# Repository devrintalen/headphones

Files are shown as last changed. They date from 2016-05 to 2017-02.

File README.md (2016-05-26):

Headphones
----------

I've always wanted to make my own headphones.  And I've wanted to tackle a more serious board design than my previous designs.  So I've tackled both with this project, codenamed NYC.

Design
======

These are no ordinary headphones.  I've built in an entire digital processing pipeline to do all sorts of crazy things.  They're essentially a set of headphones with a built-in codec—but because nobody makes open-source codecs, I've rolled my own using an FPGA.  It uses an ADC to digitize the input and a DAC to convert it back to analog, along with a hi-fi headphone amp design from Texas Instruments.

I've written a few blog posts about the design and architecture, and have a few in-depth bits about the ADC and DAC, so far.  See [this post][1], which includes an up-to-date list of the pieces I've written.

[1]: http://blog.devrintalen.net/first-draft-of-headphones/

I find the idea of having a DSP built into headphones to be pretty cool.  I don't know how I'll take advantage of that yet, but I see at least having access to an EQ over the USB connection.  Heck, maybe I'll put a bunch of knobs on the cans to give you physical access.  Anything's possible now.

Status
======

Right now the schematics have been mostly nailed down.  I'm currently laying out a development board (dubbed NYCDB-01) to test out the design and run a proof-of-concept.

Files
=====

This repository is sectioned off into the following paths:

* `docs/` is where I keep datasheets and spreadsheets.
* `pcb/` has the KiCad schematics and board layout for the development board.  In the future this will be renamed to allow there to be another folder for the product board.
* `sim/` right now has `ngspice` circuits and `gnuplot` scripts to simulate the ADC and DAC.  There's a `Makefile` in there to batch run the simulations.

Contributions
=============

Contributions are of course welcome and appreciated.  Board design is usually a one-person sport, so that may not be the best place to help out, but suggestions for the schematics are helpful.  This project is licensed under the GNU GPLv3.

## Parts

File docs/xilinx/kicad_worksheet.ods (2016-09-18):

P144 | 0 | TL | IO_L1P_HSWAPEN_0 | 0 | 0 | B | X IO_L1P_HSWAPEN_0 144 0 0 300 R 50 50 1 1 B
P143 | 0 | TL | IO_L1N_VREF_0 | 0 | 100 | B | X IO_L1N_VREF_0 143 0 100 300 R 50 50 1 1 B
P142 | 0 | TL | IO_L2P_0 | 0 | 200 | B | X IO_L2P_0 142 0 200 300 R 50 50 1 1 B
P141 | 0 | TL | IO_L2N_0 | 0 | 300 | B | X IO_L2N_0 141 0 300 300 R 50 50 1 1 B
P140 | 0 | TL | IO_L3P_0 | 0 | 400 | B | X IO_L3P_0 140 0 400 300 R 50 50 1 1 B
P139 | 0 | TL | IO_L3N_0 | 0 | 500 | B | X IO_L3N_0 139 0 500 300 R 50 50 1 1 B
P138 | 0 | TL | IO_L4P_0 | 0 | 600 | B | X IO_L4P_0 138 0 600 300 R 50 50 1 1 B
P137 | 0 | TL | IO_L4N_0 | 0 | 700 | B | X IO_L4N_0 137 0 700 300 R 50 50 1 1 B
P134 | 0 | TL | IO_L34P_GCLK19_0 | 0 | 800 | B | X IO_L34P_GCLK19_0 134 0 800 300 R 50 50 1 1 B
P133 | 0 | TL | IO_L34N_GCLK18_0 | 0 | 900 | B | X IO_L34N_GCLK18_0 133 0 900 300 R 50 50 1 1 B
P132 | 0 | TL | IO_L35P_GCLK17_0 | 0 | 1000 | B | X IO_L35P_GCLK17_0 132 0 1000 300 R 50 50 1 1 B
P131 | 0 | TL | IO_L35N_GCLK16_0 | 0 | 1100 | B | X IO_L35N_GCLK16_0 131 0 1100 300 R 50 50 1 1 B
P127 | 0 | TR | IO_L36P_GCLK15_0 | 0 | 1200 | B | X IO_L36P_GCLK15_0 127 0 1200 300 R 50 50 1 1 B
P126 | 0 | TR | IO_L36N_GCLK14_0 | 0 | 1300 | B | X IO_L36N_GCLK14_0 126 0 1300 300 R 50 50 1 1 B
P124 | 0 | TR | IO_L37P_GCLK13_0 | 0 | 1400 | B | X IO_L37P_GCLK13_0 124 0 1400 300 R 50 50 1 1 B
P123 | 0 | TR | IO_L37N_GCLK12_0 | 0 | 1500 | B | X IO_L37N_GCLK12_0 123 0 1500 300 R 50 50 1 1 B
P121 | 0 | TR | IO_L62P_0 | 0 | 1600 | B | X IO_L62P_0 121 0 1600 300 R 50 50 1 1 B
P120 | 0 | TR | IO_L62N_VREF_0 | 0 | 1700 | B | X IO_L62N_VREF_0 120 0 1700 300 R 50 50 1 1 B
P119 | 0 | TR | IO_L63P_SCP7_0 | 0 | 1800 | B | X IO_L63P_SCP7_0 119 0 1800 300 R 50 50 1 1 B
P118 | 0 | TR | IO_L63N_SCP6_0 | 0 | 1900 | B | X IO_L63N_SCP6_0 118 0 1900 300 R 50 50 1 1 B
P117 | 0 | TR | IO_L64P_SCP5_0 | 0 | 2000 | B | X IO_L64P_SCP5_0 117 0 2000 300 R 50 50 1 1 B
P116 | 0 | TR | IO_L64N_SCP4_0 | 0 | 2100 | B | X IO_L64N_SCP4_0 116 0 2100 300 R 50 50 1 1 B
P115 | 0 | TR | IO_L65P_SCP3_0 | 0 | 2200 | B | X IO_L65P_SCP3_0 115 0 2200 300 R 50 50 1 1 B
P114 | 0 | TR | IO_L65N_SCP2_0 | 0 | 2300 | B | X IO_L65N_SCP2_0 114 0 2300 300 R 50 50 1 1 B
P112 | 0 | TR | IO_L66P_SCP1_0 | 0 | 2400 | B | X IO_L66P_SCP1_0 112 0 2400 300 R 50 50 1 1 B
P111 | 0 | TR | IO_L66N_SCP0_0 | 0 | 2500 | B | X IO_L66N_SCP0_0 111 0 2500 300 R 50 50 1 1 B
P109 | NA | NA | TCK | 0 | 2600 | I | X TCK 109 0 2600 300 R 50 50 1 1 I
P110 | NA | NA | TDI | 0 | 2700 | I | X TDI 110 0 2700 300 R 50 50 1 1 I
P107 | NA | NA | TMS | 0 | 2800 | I | X TMS 107 0 2800 300 R 50 50 1 1 I
P106 | NA | NA | TDO | 0 | 2900 | O | X TDO 106 0 2900 300 R 50 50 1 1 O
P105 | 1 | RT | IO_L1P_1 | 0 | 3000 | B | X IO_L1P_1 105 0 3000 300 R 50 50 1 1 B
P104 | 1 | RT | IO_L1N_VREF_1 | 0 | 3100 | B | X IO_L1N_VREF_1 104 0 3100 300 R 50 50 1 1 B
P102 | 1 | RT | IO_L32P_1 | 0 | 3200 | B | X IO_L32P_1 102 0 3200 300 R 50 50 1 1 B
P101 | 1 | RT | IO_L32N_1 | 0 | 3300 | B | X IO_L32N_1 101 0 3300 300 R 50 50 1 1 B
P100 | 1 | RT | IO_L33P_1 | 0 | 3400 | B | X IO_L33P_1 100 0 3400 300 R 50 50 1 1 B
P99 | 1 | RT | IO_L33N_1 | 0 | 3500 | B | X IO_L33N_1 99 0 3500 300 R 50 50 1 1 B
P98 | 1 | RT | IO_L34P_1 | 0 | 3600 | B | X IO_L34P_1 98 0 3600 300 R 50 50 1 1 B
P97 | 1 | RT | IO_L34N_1 | 0 | 3700 | B | X IO_L34N_1 97 0 3700 300 R 50 50 1 1 B
P95 | 1 | RT | IO_L40P_GCLK11_1 | 0 | 3800 | B | X IO_L40P_GCLK11_1 95 0 3800 300 R 50 50 1 1 B
P94 | 1 | RT | IO_L40N_GCLK10_1 | 0 | 3900 | B | X IO_L40N_GCLK10_1 94 0 3900 300 R 50 50 1 1 B
P93 | 1 | RT | IO_L41P_GCLK9_IRDY1_1 | 0 | 4000 | B | X IO_L41P_GCLK9_IRDY1_1 93 0 4000 300 R 50 50 1 1 B
P92 | 1 | RT | IO_L41N_GCLK8_1 | 0 | 4100 | B | X IO_L41N_GCLK8_1 92 0 4100 300 R 50 50 1 1 B
P88 | 1 | RB | IO_L42P_GCLK7_1 | 0 | 4200 | B | X IO_L42P_GCLK7_1 88 0 4200 300 R 50 50 1 1 B
P87 | 1 | RB | IO_L42N_GCLK6_TRDY1_1 | 0 | 4300 | B | X IO_L42N_GCLK6_TRDY1_1 87 0 4300 300 R 50 50 1 1 B
P85 | 1 | RB | IO_L43P_GCLK5_1 | 0 | 4400 | B | X IO_L43P_GCLK5_1 85 0 4400 300 R 50 50 1 1 B
P84 | 1 | RB | IO_L43N_GCLK4_1 | 0 | 4500 | B | X IO_L43N_GCLK4_1 84 0 4500 300 R 50 50 1 1 B
P83 | 1 | RB | IO_L45P_1 | 0 | 4600 | B | X IO_L45P_1 83 0 4600 300 R 50 50 1 1 B
P82 | 1 | RB | IO_L45N_1 | 0 | 4700 | B | X IO_L45N_1 82 0 4700 300 R 50 50 1 1 B
P81 | 1 | RB | IO_L46P_1 | 0 | 4800 | B | X IO_L46P_1 81 0 4800 300 R 50 50 1 1 B
P80 | 1 | RB | IO_L46N_1 | 0 | 4900 | B | X IO_L46N_1 80 0 4900 300 R 50 50 1 1 B
P79 | 1 | RB | IO_L47P_1 | 0 | 5000 | B | X IO_L47P_1 79 0 5000 300 R 50 50 1 1 B
P78 | 1 | RB | IO_L47N_1 | 0 | 5100 | B | X IO_L47N_1 78 0 5100 300 R 50 50 1 1 B
P75 | 1 | RB | IO_L74P_AWAKE_1 | 0 | 5200 | B | X IO_L74P_AWAKE_1 75 0 5200 300 R 50 50 1 1 B
P74 | 1 | RB | IO_L74N_DOUT_BUSY_1 | 0 | 5300 | B | X IO_L74N_DOUT_BUSY_1 74 0 5300 300 R 50 50 1 1 B
P73 | NA | NA | SUSPEND | 0 | 5400 | I | X SUSPEND 73 0 5400 300 R 50 50 1 1 I
P72 | 2 | NA | CMPCS_B_2 | 0 | 5500 | N | X CMPCS_B_2 72 0 5500 300 R 50 50 1 1 N
P71 | 2 | NA | DONE_2 | 0 | 5600 | B | X DONE_2 71 0 5600 300 R 50 50 1 1 B
P70 | 2 | BR | IO_L1P_CCLK_2 | 0 | 5700 | B | X IO_L1P_CCLK_2 70 0 5700 300 R 50 50 1 1 B
P69 | 2 | BR | IO_L1N_M0_CMPMISO_2 | 0 | 5800 | B | X IO_L1N_M0_CMPMISO_2 69 0 5800 300 R 50 50 1 1 B
P67 | 2 | BR | IO_L2P_CMPCLK_2 | 0 | 5900 | B | X IO_L2P_CMPCLK_2 67 0 5900 300 R 50 50 1 1 B
P66 | 2 | BR | IO_L2N_CMPMOSI_2 | 0 | 6000 | B | X IO_L2N_CMPMOSI_2 66 0 6000 300 R 50 50 1 1 B
P65 | 2 | BR | IO_L3P_D0_DIN_MISO_MISO1_2 | 0 | 6100 | B | X IO_L3P_D0_DIN_MISO_MISO1_2 65 0 6100 300 R 50 50 1 1 B
P64 | 2 | BR | IO_L3N_MOSI_CSI_B_MISO0_2 | 0 | 6200 | B | X IO_L3N_MOSI_CSI_B_MISO0_2 64 0 6200 300 R 50 50 1 1 B
P62 | 2 | BR | IO_L12P_D1_MISO2_2 | 0 | 6300 | B | X IO_L12P_D1_MISO2_2 62 0 6300 300 R 50 50 1 1 B
P61 | 2 | BR | IO_L12N_D2_MISO3_2 | 0 | 6400 | B | X IO_L12N_D2_MISO3_2 61 0 6400 300 R 50 50 1 1 B
P60 | 2 | BR | IO_L13P_M1_2 | 0 | 6500 | B | X IO_L13P_M1_2 60 0 6500 300 R 50 50 1 1 B
P59 | 2 | BR | IO_L13N_D10_2 | 0 | 6600 | B | X IO_L13N_D10_2 59 0 6600 300 R 50 50 1 1 B
P58 | 2 | BR | IO_L14P_D11_2 | 0 | 6700 | B | X IO_L14P_D11_2 58 0 6700 300 R 50 50 1 1 B
P57 | 2 | BR | IO_L14N_D12_2 | 0 | 6800 | B | X IO_L14N_D12_2 57 0 6800 300 R 50 50 1 1 B
P56 | 2 | BR | IO_L30P_GCLK1_D13_2 | 0 | 6900 | B | X IO_L30P_GCLK1_D13_2 56 0 6900 300 R 50 50 1 1 B
P55 | 2 | BR | IO_L30N_GCLK0_USERCCLK_2 | 0 | 7000 | B | X IO_L30N_GCLK0_USERCCLK_2 55 0 7000 300 R 50 50 1 1 B
P51 | 2 | BL | IO_L31P_GCLK31_D14_2 | 0 | 7100 | B | X IO_L31P_GCLK31_D14_2 51 0 7100 300 R 50 50 1 1 B
P50 | 2 | BL | IO_L31N_GCLK30_D15_2 | 0 | 7200 | B | X IO_L31N_GCLK30_D15_2 50 0 7200 300 R 50 50 1 1 B
P48 | 2 | BL | IO_L48P_D7_2 | 0 | 7300 | B | X IO_L48P_D7_2 48 0 7300 300 R 50 50 1 1 B
P47 | 2 | BL | IO_L48N_RDWR_B_VREF_2 | 0 | 7400 | B | X IO_L48N_RDWR_B_VREF_2 47 0 7400 300 R 50 50 1 1 B
P46 | 2 | BL | IO_L49P_D3_2 | 0 | 7500 | B | X IO_L49P_D3_2 46 0 7500 300 R 50 50 1 1 B
P45 | 2 | BL | IO_L49N_D4_2 | 0 | 7600 | B | X IO_L49N_D4_2 45 0 7600 300 R 50 50 1 1 B
P44 | 2 | BL | IO_L62P_D5_2 | 0 | 7700 | B | X IO_L62P_D5_2 44 0 7700 300 R 50 50 1 1 B
P43 | 2 | BL | IO_L62N_D6_2 | 0 | 7800 | B | X IO_L62N_D6_2 43 0 7800 300 R 50 50 1 1 B
P41 | 2 | BL | IO_L64P_D8_2 | 0 | 7900 | B | X IO_L64P_D8_2 41 0 7900 300 R 50 50 1 1 B
P40 | 2 | BL | IO_L64N_D9_2 | 0 | 8000 | B | X IO_L64N_D9_2 40 0 8000 300 R 50 50 1 1 B
P39 | 2 | BL | IO_L65P_INIT_B_2 | 0 | 8100 | B | X IO_L65P_INIT_B_2 39 0 8100 300 R 50 50 1 1 B
P38 | 2 | BL | IO_L65N_CSO_B_2 | 0 | 8200 | B | X IO_L65N_CSO_B_2 38 0 8200 300 R 50 50 1 1 B
P37 | 2 | NA | PROGRAM_B_2 | 0 | 8300 | I | X PROGRAM_B_2 37 0 8300 300 R 50 50 1 1 I
P35 | 3 | LB | IO_L1P_3 | 0 | 8400 | B | X IO_L1P_3 35 0 8400 300 R 50 50 1 1 B
P34 | 3 | LB | IO_L1N_VREF_3 | 0 | 8500 | B | X IO_L1N_VREF_3 34 0 8500 300 R 50 50 1 1 B
P33 | 3 | LB | IO_L2P_3 | 0 | 8600 | B | X IO_L2P_3 33 0 8600 300 R 50 50 1 1 B
P32 | 3 | LB | IO_L2N_3 | 0 | 8700 | B | X IO_L2N_3 32 0 8700 300 R 50 50 1 1 B
P30 | 3 | LB | IO_L36P_3 | 0 | 8800 | B | X IO_L36P_3 30 0 8800 300 R 50 50 1 1 B
P29 | 3 | LB | IO_L36N_3 | 0 | 8900 | B | X IO_L36N_3 29 0 8900 300 R 50 50 1 1 B
P27 | 3 | LB | IO_L37P_3 | 0 | 9000 | B | X IO_L37P_3 27 0 9000 300 R 50 50 1 1 B
P26 | 3 | LB | IO_L37N_3 | 0 | 9100 | B | X IO_L37N_3 26 0 9100 300 R 50 50 1 1 B
P24 | 3 | LB | IO_L41P_GCLK27_3 | 0 | 9200 | B | X IO_L41P_GCLK27_3 24 0 9200 300 R 50 50 1 1 B
P23 | 3 | LB | IO_L41N_GCLK26_3 | 0 | 9300 | B | X IO_L41N_GCLK26_3 23 0 9300 300 R 50 50 1 1 B
P22 | 3 | LB | IO_L42P_GCLK25_TRDY2_3 | 0 | 9400 | B | X IO_L42P_GCLK25_TRDY2_3 22 0 9400 300 R 50 50 1 1 B
P21 | 3 | LB | IO_L42N_GCLK24_3 | 0 | 9500 | B | X IO_L42N_GCLK24_3 21 0 9500 300 R 50 50 1 1 B
P17 | 3 | LT | IO_L43P_GCLK23_3 | 0 | 9600 | B | X IO_L43P_GCLK23_3 17 0 9600 300 R 50 50 1 1 B
P16 | 3 | LT | IO_L43N_GCLK22_IRDY2_3 | 0 | 9700 | B | X IO_L43N_GCLK22_IRDY2_3 16 0 9700 300 R 50 50 1 1 B
P15 | 3 | LT | IO_L44P_GCLK21_3 | 0 | 9800 | B | X IO_L44P_GCLK21_3 15 0 9800 300 R 50 50 1 1 B
P14 | 3 | LT | IO_L44N_GCLK20_3 | 0 | 9900 | B | X IO_L44N_GCLK20_3 14 0 9900 300 R 50 50 1 1 B
P12 | 3 | LT | IO_L49P_3 | 0 | 10000 | B | X IO_L49P_3 12 0 10000 300 R 50 50 1 1 B
P11 | 3 | LT | IO_L49N_3 | 0 | 10100 | B | X IO_L49N_3 11 0 10100 300 R 50 50 1 1 B
P10 | 3 | LT | IO_L50P_3 | 0 | 10200 | B | X IO_L50P_3 10 0 10200 300 R 50 50 1 1 B
P9 | 3 | LT | IO_L50N_3 | 0 | 10300 | B | X IO_L50N_3 9 0 10300 300 R 50 50 1 1 B
P8 | 3 | LT | IO_L51P_3 | 0 | 10400 | B | X IO_L51P_3 8 0 10400 300 R 50 50 1 1 B
P7 | 3 | LT | IO_L51N_3 | 0 | 10500 | B | X IO_L51N_3 7 0 10500 300 R 50 50 1 1 B
P6 | 3 | LT | IO_L52P_3 | 0 | 10600 | B | X IO_L52P_3 6 0 10600 300 R 50 50 1 1 B
P5 | 3 | LT | IO_L52N_3 | 0 | 10700 | B | X IO_L52N_3 5 0 10700 300 R 50 50 1 1 B
P2 | 3 | LT | IO_L83P_3 | 0 | 10800 | B | X IO_L83P_3 2 0 10800 300 R 50 50 1 1 B
P1 | 3 | LT | IO_L83N_VREF_3 | 0 | 10900 | B | X IO_L83N_VREF_3 1 0 10900 300 R 50 50 1 1 B
P108 | NA | NA | GND | 0 | 11000 | W | X GND 108 0 11000 300 R 50 50 1 1 W
P113 | NA | NA | GND | 0 | 11100 | W | X GND 113 0 11100 300 R 50 50 1 1 W
P13 | NA | NA | GND | 0 | 11200 | W | X GND 13 0 11200 300 R 50 50 1 1 W
P130 | NA | NA | GND | 0 | 11300 | W | X GND 130 0 11300 300 R 50 50 1 1 W
P136 | NA | NA | GND | 0 | 11400 | W | X GND 136 0 11400 300 R 50 50 1 1 W
P25 | NA | NA | GND | 0 | 11500 | W | X GND 25 0 11500 300 R 50 50 1 1 W
P3 | NA | NA | GND | 0 | 11600 | W | X GND 3 0 11600 300 R 50 50 1 1 W
P49 | NA | NA | GND | 0 | 11700 | W | X GND 49 0 11700 300 R 50 50 1 1 W
P54 | NA | NA | GND | 0 | 11800 | W | X GND 54 0 11800 300 R 50 50 1 1 W
P68 | NA | NA | GND | 0 | 11900 | W | X GND 68 0 11900 300 R 50 50 1 1 W
P77 | NA | NA | GND | 0 | 12000 | W | X GND 77 0 12000 300 R 50 50 1 1 W
P91 | NA | NA | GND | 0 | 12100 | W | X GND 91 0 12100 300 R 50 50 1 1 W
P96 | NA | NA | GND | 0 | 12200 | W | X GND 96 0 12200 300 R 50 50 1 1 W
P129 | NA | NA | VCCAUX | 0 | 12300 | W | X VCCAUX 129 0 12300 300 R 50 50 1 1 W
P20 | NA | NA | VCCAUX | 0 | 12400 | W | X VCCAUX 20 0 12400 300 R 50 50 1 1 W
P36 | NA | NA | VCCAUX | 0 | 12500 | W | X VCCAUX 36 0 12500 300 R 50 50 1 1 W
P53 | NA | NA | VCCAUX | 0 | 12600 | W | X VCCAUX 53 0 12600 300 R 50 50 1 1 W
P90 | NA | NA | VCCAUX | 0 | 12700 | W | X VCCAUX 90 0 12700 300 R 50 50 1 1 W
P128 | NA | NA | VCCINT | 0 | 12800 | W | X VCCINT 128 0 12800 300 R 50 50 1 1 W
P19 | NA | NA | VCCINT | 0 | 12900 | W | X VCCINT 19 0 12900 300 R 50 50 1 1 W
P28 | NA | NA | VCCINT | 0 | 13000 | W | X VCCINT 28 0 13000 300 R 50 50 1 1 W
P52 | NA | NA | VCCINT | 0 | 13100 | W | X VCCINT 52 0 13100 300 R 50 50 1 1 W
P89 | NA | NA | VCCINT | 0 | 13200 | W | X VCCINT 89 0 13200 300 R 50 50 1 1 W
P122 | 0 | NA | VCCO_0 | 0 | 13300 | W | X VCCO_0 122 0 13300 300 R 50 50 1 1 W
P125 | 0 | NA | VCCO_0 | 0 | 13400 | W | X VCCO_0 125 0 13400 300 R 50 50 1 1 W
P135 | 0 | NA | VCCO_0 | 0 | 13500 | W | X VCCO_0 135 0 13500 300 R 50 50 1 1 W
P103 | 1 | NA | VCCO_1 | 0 | 13600 | W | X VCCO_1 103 0 13600 300 R 50 50 1 1 W
P76 | 1 | NA | VCCO_1 | 0 | 13700 | W | X VCCO_1 76 0 13700 300 R 50 50 1 1 W
P86 | 1 | NA | VCCO_1 | 0 | 13800 | W | X VCCO_1 86 0 13800 300 R 50 50 1 1 W
P42 | 2 | NA | VCCO_2 | 0 | 13900 | W | X VCCO_2 42 0 13900 300 R 50 50 1 1 W
P63 | 2 | NA | VCCO_2 | 0 | 14000 | W | X VCCO_2 63 0 14000 300 R 50 50 1 1 W
P18 | 3 | NA | VCCO_3 | 0 | 14100 | W | X VCCO_3 18 0 14100 300 R 50 50 1 1 W
P31 | 3 | NA | VCCO_3 | 0 | 14200 | W | X VCCO_3 31 0 14200 300 R 50 50 1 1 W
P4 | 3 | NA | VCCO_3 | 0 | 14300 | W | X VCCO_3 4 0 14300 300 R 50 50 1 1 W

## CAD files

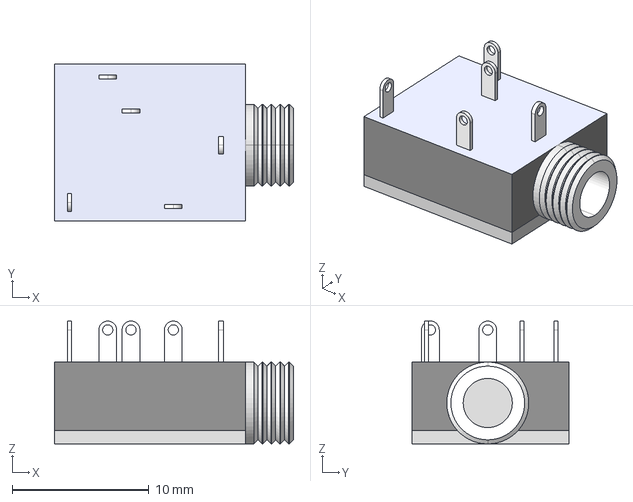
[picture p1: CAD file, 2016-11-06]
3dmodels/sj1-3515.stp
17.5 x 11.5 x 9.00 mm

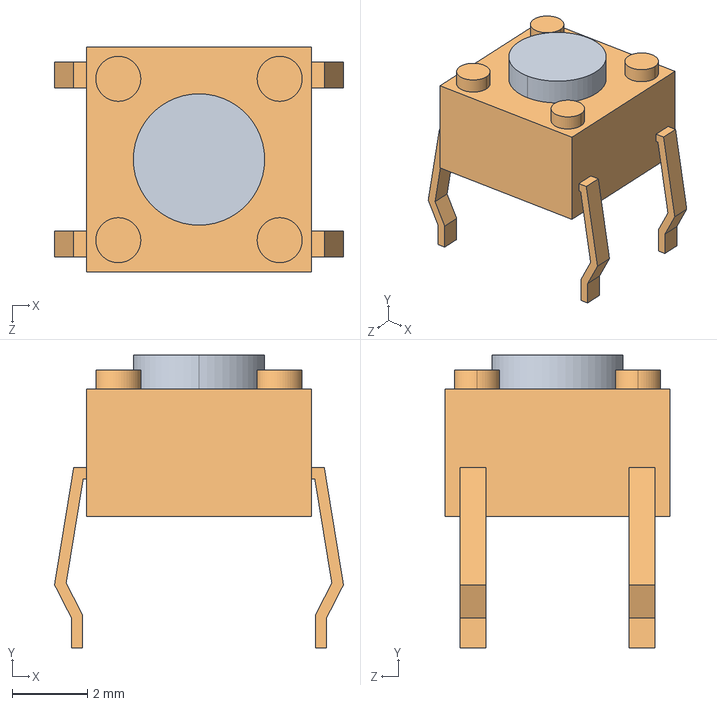
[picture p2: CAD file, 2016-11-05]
3dmodels/B3F_1000.step
7.70 x 7.80 x 6.00 mm
B3F_1000_BUTTON
B3F_1000_BASE

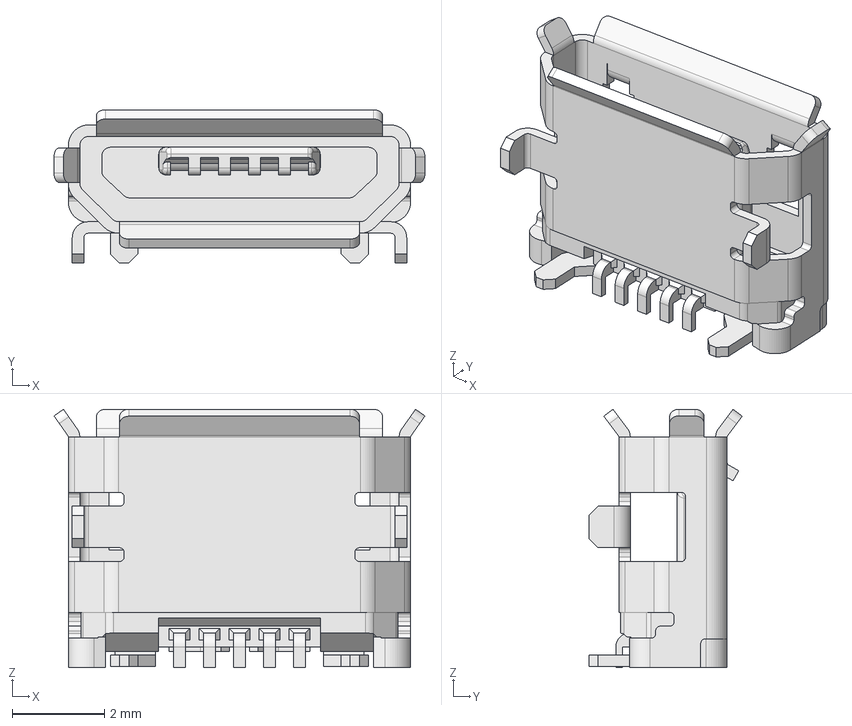
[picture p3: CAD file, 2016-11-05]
3dmodels/DX4R005JJ2R1800.fcstd
8.04 x 3.33 x 5.60 mm

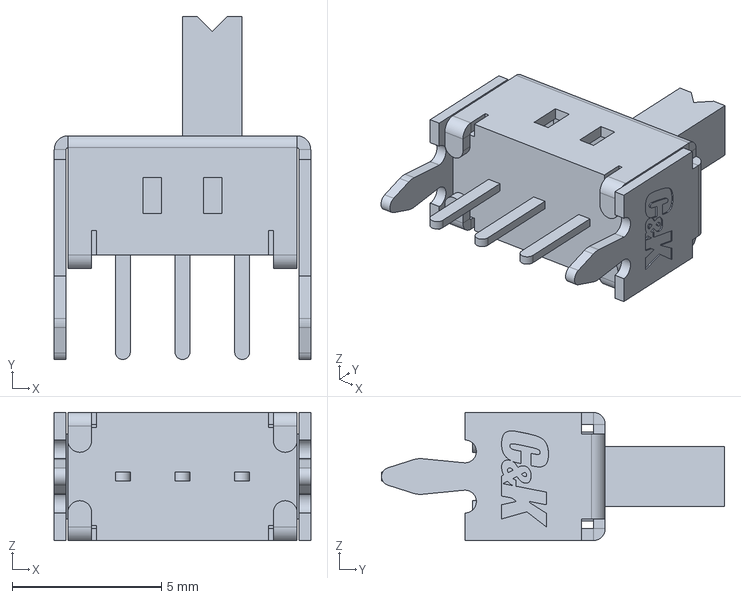
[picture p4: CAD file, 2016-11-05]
3dmodels/os-102011ms2qn1.stp
8.60 x 11.5 x 4.30 mm

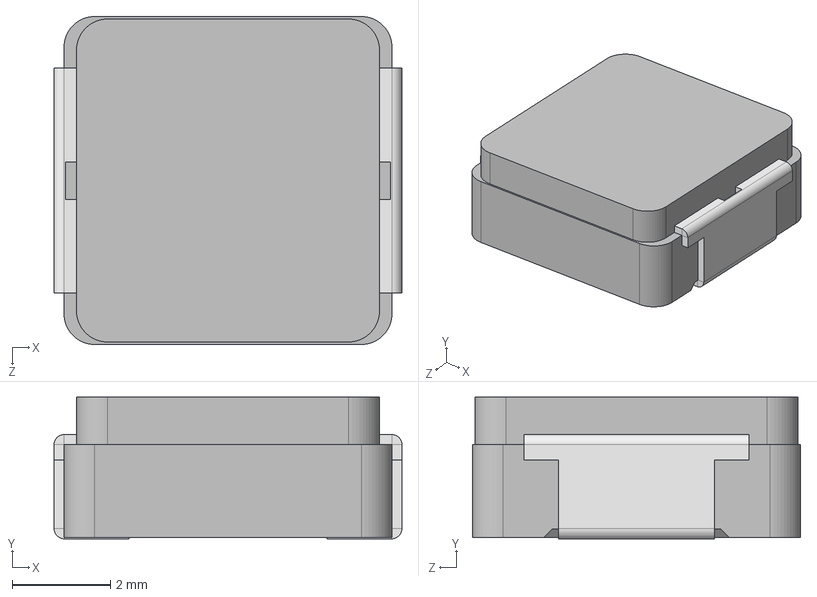
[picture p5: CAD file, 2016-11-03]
3dmodels/IHLP2525CZ.STEP
7.08 x 2.88 x 6.67 mm

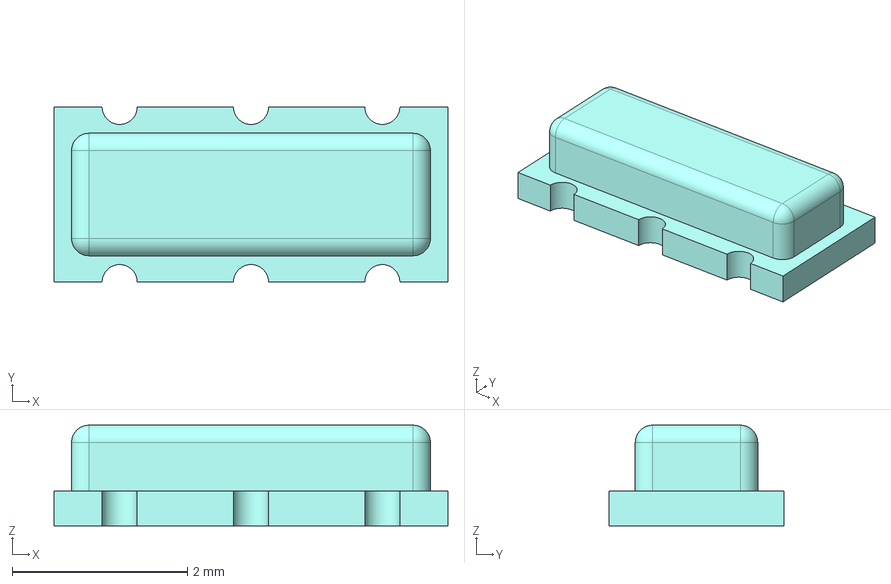
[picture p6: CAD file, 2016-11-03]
3dmodels/csctr_g.fcstd
4.50 x 2.00 x 1.15 mm

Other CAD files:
3dmodels/K3D-DX4R005JJ2-V3_JAE_Proprietary.STEP
3dmodels/b3f-1000.fcstd
3dmodels/os-102011ms2qn1.fcstd

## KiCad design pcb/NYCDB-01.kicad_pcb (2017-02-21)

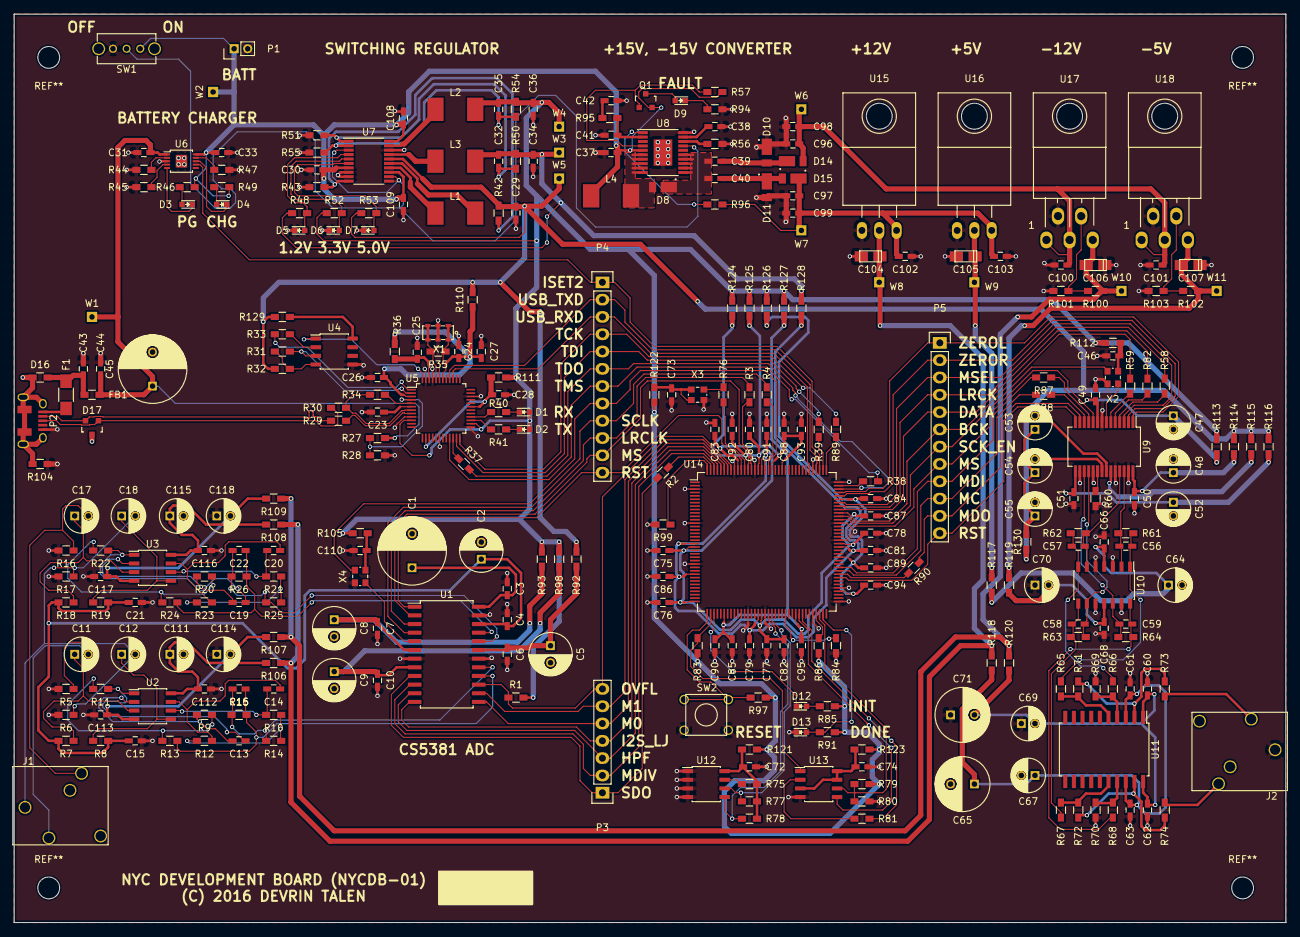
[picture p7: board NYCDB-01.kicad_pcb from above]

Board: 2 copper layers, 186.7 x 133.3 mm, 314 parts (0 on the bottom side), 202 nets.

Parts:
C1: 220uF; C_Radial_D10_L20_P5
C2, C5, C8, C9: 1uF; C_Radial_D6.3_L11.2_P2.5
C3, C4, C6, C7, C10, C43: 0.01uF; C_0603_HandSoldering
C11, C12, C17, C18, C47, C48, C52, C55, C64, C67, C69, C70, C111, C114, C115, C118: 10uF; C_Radial_D5_L11_P2
C13, C14, C19, C20: 470pF C0G; C_0603_HandSoldering
C15, C21, C24, C25, C26, C28, C38, C44, C46, C49, C50, C51, C60, C61, C62, C63, C66, C68, C72, C73, C74, C110, C112, C113, C116, C117: 0.1uF; C_0603_HandSoldering
C16, C22: 2700pF C0G; C_0603_HandSoldering
C23: 33nF; C_0603_HandSoldering
C27, C29, C34, C36, C37, C96, C97, C98, C99, C100, C101, C102, C103: 10uF; C_0603_HandSoldering
C30, C39, C40, C75, C76, C77, C78, C79, C80, C81, C82, C83, C84, C85, C86, C87, C108, C109: 4.7uF; C_0603_HandSoldering
C31, C33: 1uF; C_0603_HandSoldering
C32: 22pF; C_0603_HandSoldering
C35: 33pF; C_0603_HandSoldering
C41: 27pF; C_0603_HandSoldering
C42: 1nF; C_0603_HandSoldering
C45: 4.7uF; C_Radial_D10_L21_P5
C53, C54: 47uF; C_Radial_D5_L11_P2
C56, C57, C58, C59: 2.7nF; C_0603_HandSoldering
C65, C71: 100uF; C_Radial_D8_L11.5_P3.5
C88, C89, C90, C91, C92, C93, C94, C95: 0.47uF; C_0603_HandSoldering
C104, C105, C106, C107: 10uF TANT; TantalC_SizeS_EIA-3216
D1: RX; LED_0603
D2: TX; LED_0603
D3: PG; LED_0603
D4: CHG; LED_0603
D5: PG1V2; LED_0603
D6: PG3V3; LED_0603
D7: PG5V0; LED_0603
D8, D10, D11, D14, D15: D; POWERDI_123
D9: FAULT15V; LED_0603
D12: INIT_B; LED_0603
D13: DONE; LED_0603
D16: V5.5MLA0603H; R_0603_HandSoldering
D17: TVS_SOT23; SOT-23
F1: 1206L150; R_1206_HandSoldering
FB1: BKP1608HS330-T; R_0603_HandSoldering
J1, J2: AUDIO_JACK; SJ1-351XN
L1, L2, L3, L4: 4.7uH; IHLP-2525CZ-01
P1: CONN_BATT; Pin_Header_Straight_1x02_Pitch2.00mm
P2: SJ110578
P3: CONN_01X07; Pin_Header_Straight_1x07
P4, P5: CONN_01X12; Pin_Header_Straight_1x12
Q1: Q_PMOS_GSD; SOT-23
R1, R7, R8, R18, R19, R28, R32, R47, R60, R77, R78: 10K; R_0603_HandSoldering
R2, R3, R4, R37, R38, R39, R58, R59, R76, R81, R82, R87, R88, R89, R90: 68; R_0603_HandSoldering
R5, R6, R16, R17, R51, R57: 100K; R_0603_HandSoldering
R9, R10, R20, R21: 634; R_0603_HandSoldering
R11, R12, R22, R23: 91; R_0603_HandSoldering
R13, R14, R15, R24, R25, R26: 200; R_0603_HandSoldering
R27, R79, R80, R85, R97: 4.7K; R_0603_HandSoldering
R29, R30: 27; R_0603_HandSoldering
R31: 2.2K; R_0603_HandSoldering
R33: 30; R_0603_HandSoldering
R34, R46, R49: 1.5K; R_0603_HandSoldering
R35: 1M; R_0603_HandSoldering
R36: 470; R_0603_HandSoldering
R40, R41: 220; R_0603_HandSoldering
R42: 121K; R_0603_HandSoldering
R43: 16.5K; R_0603_HandSoldering
R44, R45, R61, R62, R63, R64, R65, R66, R67, R68, R69, R70, R71, R72: 1K; R_0603_HandSoldering
R48, R52, R53: 294; R_0603_HandSoldering
R50: 102K; R_0603_HandSoldering
R54: 274K; R_0603_HandSoldering
R55: 60.4K; R_0603_HandSoldering
R56: 86.6K; R_0603_HandSoldering
R73, R74: 39.2; R_0603_HandSoldering
R75, R84, R86, R99, R104: 0; R_0603_HandSoldering
R83: 2.4K; R_0603_HandSoldering
R91: 330; R_0603_HandSoldering
R92, R93, R98, R105, R106, R107, R108, R109, R110, R111, R112, R113, R114, R115, R116, R117, R118, R119, R120, R121, R122, R123, R124, R125, R126, R127, R128, R129, R130: 0.1; R_0603_HandSoldering
R94: 422; R_0603_HandSoldering
R95: 34K; R_0603_HandSoldering
R96: 165K; R_0603_HandSoldering
R100: 107K; R_0603_HandSoldering
R101, R103: 12.1K; R_0603_HandSoldering
R102: 37.4K; R_0603_HandSoldering
SW1: SW_POWER; SWITCH_SPDT_OS
SW2: SW_RESET; SW_PUSH_6X6
U1: CS5361; SOIC-24_7.5x15.4mm_Pitch1.27mm
U2, U3: OP1642; SOIC-8_3.9x4.9mm_Pitch1.27mm
U4: 93CxxA; SOIC-8_3.9x4.9mm_Pitch1.27mm
U5: FT2232D; LQFP-48_7x7mm_Pitch0.5mm
U6: bq2409x; MSOP-10-1EP_3x3mm_Pitch0.5mm
U7: LTC3521; TSSOP-20_4.4x6.5mm_Pitch0.65mm
U8: LT3579; TSSOP-20_4.4x6.5mm_Pitch0.65mm_Pad
U9: PCM1792A; SSOP-28_5.3x10.2mm_Pitch0.65mm
U10: OPA4134; SOIC-14_3.9x8.7mm_Pitch1.27mm
U11: TPA6120A2; SOIC-20_7.5x12.8mm_Pitch1.27mm
U12: 24C16; SOIC-8_3.9x4.9mm_Pitch1.27mm
U13: M25P40; SOIC-8_3.9x4.9mm_Pitch1.27mm
U14: XC6SLX9TQG144; TQFP-144_20x20mm_Pitch0.5mm
U15: LT1086CT-12; TO-220_Neutral123_Horizontal
U16: LT1086CT-5; TO-220_Neutral123_Horizontal
U17, U18: LT3015ET-ADJ; Pentawatt_Neutral_Staggered-Typ1_Horizontal_TO220-5-TA05B
W1, W2, W3, W4, W5, W6, W7, W8, W9, W10, W11: TEST_1P; Measurement_Point_Square-TH_Small
X1: 6MHz; CSCTR_G
X2, X3, X4: 12.288MHz; Oscillator_SMD_2520_4Pads

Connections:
+1V2: C32.1, C34.1, L3.2, R48.1, R50.1, R128.2, W3.1
+3V3: C35.1, C36.1, D1.2, D2.2, L2.2, R1.2, R52.1, R54.1, R79.1, R83.1, R85.1, R86.1, R91.1, R93.1, R97.1, R98.1, R105.1, R111.1, R112.2, R113.2, R121.2, R122.2, R123.2, R124.2, R125.2, R126.2, R127.2, U5.10, U5.26, W4.1
+5V: C29.1, R32.1, R42.1, R53.1, R92.2, R110.2, R114.2, R115.1, R116.1, R129.2, R130.2, U7.16, W5.1
+5VA: C105.1, R117.2, U16.2, W9.1
+12VA: C104.1, R106.2, R108.2, R118.2, U15.2, W8.1
+15V: C97.1, C99.1, C102.1, C103.1, D15.1, R96.1, U15.3, U16.3, W7.1
-5VA: C107.2, R102.1, R119.1, U18.5, W11.1
-12VA: C106.2, R100.1, R107.1, R109.1, R120.1, U17.5, W10.1
-15V: C96.1, C98.1, C100.1, C101.1, D14.2, U17.1, U17.3, U18.1, U18.3, W6.1
/CS5361 ADC/ADC_HPF: P3.3, U1.11, U14.141
/CS5361 ADC/ADC_I2S_LJ: P3.4, U1.12, U14.140
/CS5361 ADC/ADC_LRCLK: P4.10, R3.2, U1.3
/CS5361 ADC/ADC_M0: P3.5, U1.13, U14.139
/CS5361 ADC/ADC_M1: P3.6, U1.14, U14.138
/CS5361 ADC/ADC_MCLK_EN: P4.8, U14.126, X4.1
/CS5361 ADC/ADC_MDIV: P3.2, U1.10, U14.142
/CS5361 ADC/ADC_MS: P4.11, U1.2, U14.132
/CS5361 ADC/ADC_OVFL: P3.7, R1.1, U1.15, U14.137
/CS5361 ADC/ADC_RST: P4.12, U1.1, U14.134
/CS5361 ADC/ADC_SCLK: P4.9, R4.2, U1.4
/CS5361 ADC/ADC_SDO: P3.1, R2.2, U1.9
/CS5361 ADC/ING: C12.2, C18.2, J1.1, R6.1, R17.1
/CS5361 ADC/INL: C11.2, J1.2, R5.1
/CS5361 ADC/INR: C17.2, J1.3, R16.1
/CS5361 ADC/left buffer/+12L: C111.1, C112.2, R106.1, U2.8
/CS5361 ADC/left buffer/-12L: C113.2, C114.2, R107.2, U2.4
/CS5361 ADC/left buffer/AIN+: C16.1, R13.1, R15.2, U1.16
/CS5361 ADC/left buffer/AIN-: C16.2, R14.1, R15.1, U1.17
/CS5361 ADC/left buffer/VQ: C2.1, C4.2, C15.2, C21.2, R7.2, R8.1, R18.2, R19.1, U1.22
/CS5361 ADC/right buffer/+12L: C115.1, C116.2, R108.1, U3.8
/CS5361 ADC/right buffer/-12L: C117.2, C118.2, R109.2, U3.4
/CS5361 ADC/right buffer/AIN+: C22.1, R24.1, R26.2, U1.21
/CS5361 ADC/right buffer/AIN-: C22.2, R25.1, R26.1, U1.20
/FT2232D/D+: D17.1, P2.3, R30.2
/FT2232D/D-: D17.2, P2.2, R29.2
/FT2232D/TCK: P4.4, R89.1, U5.24
/FT2232D/TDI: P4.5, R39.1, U5.23
/FT2232D/TDO: P4.6, R37.2, U14.106
/FT2232D/TMS: P4.7, R38.1, U5.21
/FT2232D/USB5V: C31.1, C44.2, C45.1, FB1.1, R27.2, U6.1, W1.1
/FT2232D/USBD+: R30.1, R34.1, U5.7
/FT2232D/USBD-: R29.1, U5.8
/FT2232D/USB_RXD: P4.3, U5.39, U14.114
/FT2232D/USB_TXD: P4.2, U5.40, U14.112
/Power Supplies/ISET2: P4.1, U6.7, U14.111
/Power Supplies/PWR_SW: SW1.2, U7.3, U7.11, U7.12, U8.17
/Power Supplies/V_BATT: C30.1, C33.1, C37.1, C108.1, C109.1, L4.1, P1.1, Q1.2, R46.2, R49.2, R57.2, SW1.1, U6.10, U7.7, U7.13, U7.20, U8.5, W2.1
/TI DAC/+5VL: C64.1, C66.2, R117.1, U10.4
/TI DAC/+12VL: C61.2, C63.2, C65.1, C67.1, R118.1, U11.3, U11.18
/TI DAC/-5VL: C68.2, C70.2, R119.2, U10.11
/TI DAC/-12VL: C60.2, C62.2, C69.2, C71.2, R120.2, U11.1, U11.20
/TI DAC/DAC_BCK: P5.6, R59.2, U14.99
/TI DAC/DAC_DATA: P5.5, R82.2, U14.100
/TI DAC/DAC_LRCK: P5.4, R58.2, U14.101
/TI DAC/DAC_MC: P5.10, R88.2, U14.82
/TI DAC/DAC_MDI: P5.9, R87.2, U14.83
/TI DAC/DAC_MDO: P5.11, R90.2, U9.13
/TI DAC/DAC_MS: P5.8, U9.10, U14.97
/TI DAC/DAC_MSEL: P5.3, U9.3, U14.102
/TI DAC/DAC_RST: P5.12, U9.14, U14.80
/TI DAC/DAC_SCK_EN: P5.7, U14.98, X2.1
/TI DAC/DAC_ZEROL: P5.1, U9.1, U14.105
/TI DAC/DAC_ZEROR: P5.2, U9.2, U14.104
/TI DAC/OUTL: J2.2, R73.1
/TI DAC/OUTR: J2.3, R74.1
/XC6SLX9 FPGA/VCCAUX: C75.1, C76.1, C77.1, C78.1, C80.1, C82.1, C87.1, C92.1, R124.1, U14.20, U14.36, U14.53, U14.90, U14.129
/XC6SLX9 FPGA/VCCINT: C79.1, C81.1, C86.1, C91.1, R128.1, U14.19, U14.28, U14.52, U14.89, U14.128
/XC6SLX9 FPGA/VCCO_0: C83.1, C88.1, C93.1, R125.1, U14.122, U14.125, U14.135
/XC6SLX9 FPGA/VCCO_1: C84.1, C89.1, C94.1, R126.1, U14.76, U14.86, U14.103
/XC6SLX9 FPGA/VCCO_2: C85.1, C90.1, C95.1, R127.1, U14.42, U14.63
GND: C1.2, C2.2, C3.2, C4.1, C5.2, C6.2, C7.2, C8.2, C9.2, C10.2, C15.1, C21.1, C23.2, C24.2, C25.2, C26.2, C27.2, C28.2, C29.2, C30.2, C31.2, C33.2, C34.2, C36.2, C37.2, C38.2, C41.2, C42.2, C43.2, C44.1, C45.2, C46.2, C47.2, C48.2, C49.2, C50.2, C51.2, C52.2, C55.2, C60.1, C61.1, C62.1, C63.1, C64.2, C65.2, C66.1, C67.2, C68.1, C69.1, C70.1, C71.1, C72.2, C73.2, C74.2, C75.2, C76.2, C77.2, C78.2, C79.2, C80.2, C81.2, C82.2, C83.2, C84.2, C85.2, C86.2, C87.2, C88.2, C89.2, C90.2, C91.2, C92.2, C93.2, C94.2, C95.2, C96.2, C97.2, C98.2, C99.2, C100.2, C101.2, C102.2, C103.2, C104.2, C105.2, C106.1, C107.1, C108.2, C109.2, C110.2, C111.2, C112.1, C113.1, C114.1, C115.2, C116.1, C117.1, C118.1, D5.1, D6.1, D7.1, D10.1, D11.2, D13.1, J2.1, P1.2, P2.5, R5.2, R6.2, R16.2, R17.2, R28.1, R43.2, R44.2, R45.2, R47.1, R51.2, R55.2, R56.2, R60.1, R69.1, R70.1, R80.2, R84.2, R94.2, R99.2, R101.2, R103.2, R104.1, SW1.3, SW2.2, U1.7, U1.18, U1.23, U4.5, U5.9, U5.18, U5.25, U5.34, U5.45, U5.47, U6.3, U6.11, U7.8, U7.9, U7.18, U8.20, U8.PAD, U9.8, U9.16, U9.19, U9.24, U9.27, U10.3, U10.5, U10.10, U10.13, U12.1, U12.2, U12.3, U12.4, U13.4, U14.3, U14.13, U14.25, U14.49, U14.54, U14.68, U14.73, U14.77, U14.91, U14.96, U14.108, U14.113, U14.130, U14.136, U15.1, U16.1, U17.2, U18.2, X1.2, X2.2, X3.2, X4.2
GNDPWR: D16.1, D17.3, P2.6, P2.7, P2.8, P2.9, P2.10, P2.11, R104.2
unnamed: C1.1, C3.1, U1.24
unnamed: C5.1, C6.1, R92.1, U1.19
unnamed: C7.1, C8.1, R93.2, U1.6
unnamed: C9.1, C10.1, R98.2, U1.8
unnamed: C11.1, R7.1, U2.3
unnamed: C12.1, R8.2, U2.5
unnamed: C13.1, R11.2, U2.1
unnamed: C13.2, R9.2, U2.2
unnamed: C14.1, R12.1, U2.7
unnamed: C14.2, R10.2, U2.6
unnamed: C17.1, R18.1, U3.3
unnamed: C18.1, R19.2, U3.5
unnamed: C19.1, R22.2, U3.1
unnamed: C19.2, R20.2, U3.2
unnamed: C20.1, R23.1, U3.7
unnamed: C20.2, R21.2, U3.6
unnamed: C23.1, U5.6
unnamed: C24.1, C26.1, C27.1, R36.1, R110.1, U5.3, U5.42
unnamed: C25.1, R36.2, U5.46
unnamed: C28.1, R111.2, U5.14, U5.31
unnamed: C32.2, R50.2, R51.1, U7.1
unnamed: C35.2, R54.2, R55.1, U7.2
unnamed: C38.1, U8.19
unnamed: C39.1, D10.2, D14.1
unnamed: C39.2, C40.2, D8.1, U8.11, U8.12, U8.13, U8.14, U8.15
unnamed: C40.1, D11.1, D15.2
unnamed: C41.1, R95.1, U8.2
unnamed: C42.1, R95.2
unnamed: C43.1, D16.2, F1.2, FB1.2
unnamed: C46.1, R112.1, X2.4
unnamed: C47.1, C49.1, R113.1, U9.9
unnamed: C48.1, C50.1, R114.1, U9.28
unnamed: C51.1, C52.1, R116.2, U9.15
unnamed: C53.1, C54.1, C55.1, R130.1
unnamed: C53.2, U9.22
unnamed: C54.2, U9.21
unnamed: C56.1, R61.1, R65.2, U10.1
unnamed: C56.2, R61.2, U9.26, U10.2
unnamed: C57.1, R62.1, R66.2, U10.7
unnamed: C57.2, R62.2, U9.25, U10.6
unnamed: C58.1, R63.1, R67.2, U10.8
unnamed: C58.2, R63.2, U9.18, U10.9
unnamed: C59.1, R64.1, R68.2, U10.14
unnamed: C59.2, R64.2, U9.17, U10.12
unnamed: C72.1, R75.1, R77.1, R78.1, R121.1, U12.8
unnamed: C73.1, R122.1, X3.1, X3.4
unnamed: C74.1, R123.1, U13.3, U13.7, U13.8
unnamed: C110.1, R105.2, X4.4
unnamed: D1.1, R40.1
unnamed: D2.1, R41.1
unnamed: D3.1, U6.5
unnamed: D3.2, R46.1
unnamed: D4.1, U6.8
unnamed: D4.2, R49.1
unnamed: D5.2, R48.2, U7.4
unnamed: D6.2, R52.2, U7.5
unnamed: D7.2, R53.2, U7.6
unnamed: D8.2, L4.2, U8.6, U8.7, U8.8, U8.9, U8.10
unnamed: D9.1, R94.1
unnamed: D9.2, Q1.3
unnamed: D12.1, U14.39
unnamed: D12.2, R85.2
unnamed: D13.2, R91.2, U14.71
unnamed: F1.1, P2.1
unnamed: L1.1, U7.14
unnamed: L1.2, U7.15
unnamed: L2.1, U7.19
unnamed: L3.1, U7.17
unnamed: Q1.1, R57.1, U8.4
unnamed: R2.1, U14.143
unnamed: R3.1, U14.131
unnamed: R4.1, U14.127
unnamed: R10.1, R12.2, R14.2
unnamed: R9.1, R11.1, R13.2
unnamed: R20.1, R22.1, R24.2
unnamed: R21.1, R23.2, R25.2
unnamed: R27.1, R28.2, U5.4
unnamed: R31.1, U4.3, U5.2
unnamed: R31.2, R32.2, U4.4
unnamed: R33.1, U5.1
unnamed: R33.2, U4.2
unnamed: R34.2, U5.5
unnamed: R35.1, U5.43, X1.1
unnamed: R35.2, U5.44, X1.3
unnamed: R37.1, U5.22
unnamed: R38.2, U14.107
unnamed: R39.2, U14.110
unnamed: R40.2, U5.28
unnamed: R41.2, U5.27
unnamed: R42.2, R43.1, U7.10
unnamed: R44.1, U6.2
unnamed: R45.1, U6.4
unnamed: R47.2, U6.9
unnamed: R56.1, U8.18
unnamed: R58.1, U9.4
unnamed: R59.1, U9.6
unnamed: R60.2, U9.20
unnamed: R65.1, R71.2, U11.5
unnamed: R66.1, R69.2, U11.4
unnamed: R67.1, R72.2, U11.16
unnamed: R68.1, R70.2, U11.17
unnamed: R71.1, R73.2, U11.2
unnamed: R72.1, R74.2, U11.19
unnamed: R75.2, U12.7
unnamed: R76.1, U14.133
unnamed: R76.2, X3.3
unnamed: R77.2, U12.6, U14.56
unnamed: R78.2, U12.5, U14.55
unnamed: R79.2, R80.1, U13.6, U14.70
unnamed: R81.1, U13.2
unnamed: R81.2, U14.65
unnamed: R82.1, U9.5
unnamed: R83.2, U13.1, U14.38
unnamed: R84.1, U14.60
unnamed: R86.2, U14.69
unnamed: R87.1, U9.11
unnamed: R88.1, U9.12
unnamed: R89.2, U14.109
unnamed: R90.1, U14.81
unnamed: R96.2, U8.1
unnamed: R97.2, SW2.1, U14.37
unnamed: R99.1, U14.144
unnamed: R100.2, R101.1, U17.4
unnamed: R102.2, R103.1, U18.4
unnamed: R115.2, U9.23
unnamed: R129.1, U4.8
unnamed: U1.5, X4.3
unnamed: U4.1, U5.48
unnamed: U9.7, X2.3
unnamed: U13.5, U14.64

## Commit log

2015-01-16 Initial commit
    - Includes CS4398 schematic (and output filters)
    - Includes some documentation
    [cs4398.sch, dac_output_filter.sch]
2015-01-18 Work in progress
    - Added CS48540 schematic, not done yet
    - Minor tweaks to CS4398 schematic
    - Fixed the origin offset for the DAC filter symbol
    [cs4398.sch, cs48540.sch]
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2015-01-18 Finished CS48540 schematic (for now) and added a doc
    [cs48540.sch]
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2015-01-25 Reorganized the project directory
    - Moved all symbols to sym/
    - Created a top-level top.sch that brings together the multi-page
    schematic.
    - Brought in symbols that were previously in a different component
    library path.
    [digital_signal_processing.sch, input_adc_stage.sch, output_dac_stage.sch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]
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2015-01-31 Added in the power design
    - Renamed the power nets throughout the design
    - Added symbols for Linear symbols
    - Added datasheets
    [digital_signal_processing.sch, input_adc_stage.sch, output_dac_stage.sch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]
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2015-02-07 New microcontroller sheet
    - Provides control signals and I2C
    - Modified top.sym to include it
    - Added relevant docs
    [microcontroller.sch]
2015-02-09 Made a few tweaks
    - Separated the ground of the input jack from the normal ground plane
    - Added a jack detect signal out to the micro
    [input_adc_stage.sch, microcontroller.sch]
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2015-02-10 Cleaning up some DRC errors
    [input_adc_stage.sch]
2015-02-11 WIP fixing DRC errors
    - Fixed most unconnected nets
    - Fixed a lot of the net= attributes
    - Still have more DRC errors to clean up
    [digital_signal_processing.sch, input_adc_stage.sch, microcontroller.sch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]
2015-02-11 WIP fixing DRC errors
    - Fixed slot errors
    - Fixed pintype errors
    [output_dac_stage.sch]
2015-02-11 Fixed slotted refdes that I broke
    [input_adc_stage.sch, output_dac_stage.sch]
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2015-04-23 First pass at FPGA schematic, not complete yet
    [fpga.sch]
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2015-04-27 Fixed aesthetic error with stray attribute
    [top.sch]
2015-04-27 A few changes
    - Updated Makefile and project file to include the right sheets
    - Switched to grenum (rather than refdes_renum) in the Makefile
    - Ran grenum, fpga and usb_input schematics got annotated
    [fpga.sch, usb_input.sch]
2015-04-27 Added footprints, missing USB connector
    [usb_input.sch]
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2015-04-30 Added oscillator footprint
    [fpga.sch]
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2015-05-01 Updates to the FPGA
    - Added recommended decoupling as per UG393
    - Added termination and pullup resistors to SPI flash
    - Fixed up some of the configuration pins as per UG380
    - Added I2C pullups
    [fpga.sch]
2015-05-01 Updates to input ADC
    - Picked dual op-amp device
    - Chose footprints for all resistors and caps
    - Created 3.5mm jack footprint
    [input_adc_stage.sch]
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2015-05-02 Aesthetic fix
    [usb_input.sch]
2015-05-02 DRC fixes for schematics
    - Fixed 1.2V netname
    - Re-annotated schematics
    - Fixed single-ended nets
    - Fixed unused slots
    There are still errors outstanding for all the unconnected pins on the
    FPGA (and others), but everything else is clean. There are warnings for
    mixed pintypes where I've tied an input pin to Vcc or GND or whatnot.
    [fpga.sch, input_adc_stage.sch, output_dac_stage.sch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]
2015-07-16 Fixed footprint for FPGA
    [fpga.sch]
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2016-01-28 Switched to Kicad for design
    The entire schematic design has been recreated in Kicad, plus a few
    improvements.
    [001.kicad_pcb, 001.sch, analog_input_buffer.sch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]
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2016-01-29 Added a second SPI device
    This second SPI slave will store the DSP program code. I've added
    it in a SPI daisy-chain with the configuration SPI device. Will
    need to do some investigating into proper termination for the MISO
    line.
    [001.sch, xc6slx9.sch]
2016-01-30 Revert "Added a second SPI device"
    This reverts commit 218bd654e3ca6c6a8cae487fb597d871c261f046.
    I think an i2c ROM may be more suitable.
    [001.sch, xc6slx9.sch]
2016-01-30 Added i2c ROM to FPGA
    This ROM is for the DSP program instructions. Other changes:
    - Increased the sheet size to 11x17
    - Moved the oscillator symbol over to bank 0
    - Repositioned the symbol blocks to spread things out
    [xc6slx9.sch]
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2016-02-06 Fixing voltage rails
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2016-04-05 Ditched CS4398 for TI solution
    Cirrus DAC and amp have been replaced by TI parts PCM1792A, OPA4134,
    and TPA6120A2. I followed the reference hi-fi schematic in the
    tpa6120a2 datasheet.
    [001.sch, analog_input_buffer.sch, cs4398.sch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]
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2016-04-05 Began cleaning up ERC errors
    [001.sch, analog_input_buffer.sch, cs5361.sch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]
2016-04-11 Cleaned up power supplies
    - Finished the FAULT LED driver
    - Annotated the schematics
    - Started updating the power consumption spreadsheet
    [001.sch, analog_input_buffer.sch, cs5361.sch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]
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2016-04-25 Reworked power spreadsheet
    [power_consumption.ods]
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2016-04-29 Picked a footprint for the inverting LDOs
    [power_supplies.sch]
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2016-05-02 Swapped DNS cap for 0-ohm resistor
    [usb_conn.sch]
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2016-05-07 Fixing up some part numbers
    [001.sch, cs5361.sch, ft2232d.sch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]
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2016-05-07 Fixed new ERC warning
    [analog_input_buffer.sch, ti_dac.sch, usb_conn.sch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]
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2016-05-19 Laid out some of the ADC
    Had to flip a resistor around on the schematic to make routing a
    little cleaner, which also affected the netlist.
    [NYCDB-01.kicad_pcb, analog_input_buffer.sch]
2016-05-19 Finished laying out a lot of the ADC
    [NYCDB-01.kicad_pcb, cs5361.sch]
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2016-05-22 Moved the USB connector to a better spot
    [NYCDB-01.kicad_pcb]
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2016-05-26 Reworking some of the ADC->FPGA traces
    [NYCDB-01.kicad_pcb]
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2016-05-27 Finished pin swapping the FPGA ADC signals
    Still not super jazzed about how coupled the ADC I2S traces are, and I
    need to look into the MCLK situation for the ADC. Ideally the FPGA
    shouldn't be generating it since it's a lousy clock driver. Will
    probably need another oscillator for the ADC same as the FPGA and DAC.
    [NYCDB-01.kicad_pcb, xc6slx9.sch]
2016-05-27 Added an oscillator for the ADC
    [NYCDB-01.kicad_pcb, NYCDB-01.sch, analog_input_buffer.sch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]
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2016-05-29 Replaced output test pads with an audio jack
    [NYCDB-01.kicad_pcb, NYCDB-01.sch, xc6slx9.sch]
2016-05-30 Fixed placement of series termination resistors
    I had the logical placement of the series termination resistors wrong
    in the schematics (i.e. I had them placed at the source rather than
    the load) so I moved all those around to the correct sheets. I also
    moved the ADC resistors in the layout, but haven't gotten to the DAC
    ones yet.
    [NYCDB-01.kicad_pcb, cs5361.sch, ti_dac.sch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]
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2016-05-30 Cleaned up a lot of the FT2232D->FPGA connections
    Moved the series termination resistors into the right spots and
    cleaned up and aligned all the traces to the FPGA.
    [NYCDB-01.kicad_pcb, NYCDB-01.sch, analog_input_buffer.sch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]
2016-05-30 Connected the DAC to the FPGA
    Re-pinned out the DAC signals on the FPGA to clean up the routing and
    made all the connections. Tried to space out the traces cleanly.
    [NYCDB-01.kicad_pcb, NYCDB-01.sch, analog_input_buffer.sch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]
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2016-06-01 Updated 0603 footprints
    Changed to 0603 "handsoldering" versions of the footprints to make my
    life easier when assembling everything. The schematic and PCB
    footprints have been updated but the layout hasn't been fixed and
    currently fails DRC.
    [NYCDB-01.kicad_pcb]
2016-06-02 Starting to fix up some of the DRC errors
    [NYCDB-01.kicad_pcb]
2016-06-03 Fixing up some tracks
    [NYCDB-01.kicad_pcb]
2016-06-04 Cleaned up a lot of the ADC input tracks
    [NYCDB-01.kicad_pcb]
2016-06-05 Still fixing errors
    [NYCDB-01.kicad_pcb]
2016-06-05 Cleaned up most of the FPGA errors
    [NYCDB-01.kicad_pcb]
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2016-06-06 Cleaned up DRC errors from new 0603 footprints
    [NYCDB-01.kicad_pcb]
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2016-06-08 Added some missing ground vias
    [NYCDB-01.kicad_pcb]
2016-06-08 Tightened up the LDOs a bit
    [NYCDB-01.kicad_pcb]
2016-06-09 Tightened up the inverting regulator a bit
    [NYCDB-01.kicad_pcb]
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2016-06-21 Fixing up USB connector
    - Had to go back through and re-annotate all the 0603 caps and
    resistors to the hand-solderding versions since those changes didn't
    make it back into the schematics the last time I tried.
    - Added a new footprint for the USB connector to connect to all the
    shield pins.
    [NYCDB-01.kicad_pcb, analog_input_buffer.sch, cs5361.sch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]
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2016-10-20 Finished routing everything
    There's a single unconnected net somewhere that even the DRC checker
    can't find. Not sure what to do about it.
    [NYCDB-01.kicad_pcb]
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2016-10-29 Fixed DFM errors
    Ran the board through Advanced Circuits' freedfm.com service and
    cleaned up all the DFM warnings and errors.
    [NYCDB-01.kicad_pcb]
2016-11-03 Added some 3D models to footprints
    The following have gotten 3D models:
    - CSCTR_G
    - IHLP-2525CZ-01
    - POWERDI_123
    - SJ1-351XN
    - SJ110578
    [IHLP2525CZ.STEP, K3D-DX4R005JJ2-V3_JAE_Proprietary.STEP, NYCDB-01.kicad_pcb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]
2016-11-05 Finished adding 3d models
    Added the following:
    - B3F-1000
    - DX4R005JJ2
    - OS-102011
    Also added some documentation for the slide switch and updated the
    layout to use the new footprints. I moved the USB connector a bit
    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
    [B3F_1000.step, DX4R005JJ2R1800.fcstd, NYCDB-01.kicad_pcb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]
2016-11-06 3D model updates
    Moved 3D files out to the system packages3d/ folder instead of local to
    the project.
    [sj1-3515.stp]
2016-11-06 Reloaded updated footprints on board
    Reloaded the footprints that I just modified the 3d models for so they
    show up.
    [NYCDB-01.kicad_pcb]
2016-11-07 Cleanup and added testpoints
    Cleaned up some of the schematic layout without changing any nets. Also
    added testpoints to all the power rails for easy debug.
    [NYCDB-01.kicad_pcb, NYCDB-01.sch, analog_input_buffer.sch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]
2016-11-07 More cleanup and switched sense resistors
    Increased the resistance of the current sense resistors up to 0.1 ohm.
    [analog_input_buffer.sch, cs5361.sch, ft2232d.sch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]
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2017-02-10 Adjusted USB diff pair spacing
    Based on a 32mil board the spacing actually needs to be about 16mil to
    hit the 90ohm impedance.
    [NYCDB-01.kicad_pcb]
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2017-02-11 Traces on a plane
    - Finished placing testpoints and got footprints for them
    - Cleaned up the last of the unconnected tracks
    - Switched up supply rails for PWRGOOD LEDs
    [NYCDB-01.kicad_pcb, NYCDB-01.sch, analog_input_buffer.sch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]
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

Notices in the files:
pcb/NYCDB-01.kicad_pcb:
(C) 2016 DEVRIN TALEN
